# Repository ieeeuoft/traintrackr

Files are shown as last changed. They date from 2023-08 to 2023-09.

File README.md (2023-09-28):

# Traintracker
Traintracker is an interactive way to track regional GO trains on the Lakeshore West and Lakeshore East GO rail corridors. Built using a custom-made PCB that communicates to an API providing real-time train data, this project combines all aspects of electrical engineering, from circuitry to embedded design and programming to software backend systems. 

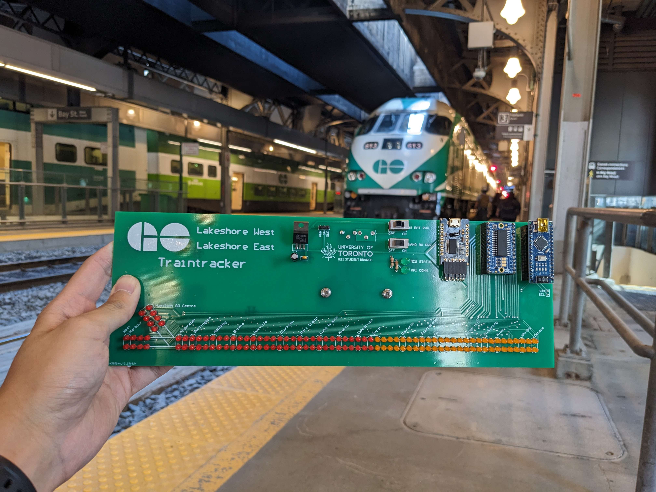
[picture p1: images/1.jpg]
gotrain


##  How It Works
Real-time train locations are displayed on a custom PCB with 130 LEDs representing a rough to-scale map of the two GO train lines. Real-time train location coordinates are pulled from the official GO transit API using a Python script and then sent serially to an Arduino Nano. The Arduino Nano then communicates via I2C an LED driver which powers the LED map. 

The PCB has its own built-in power source - all that is needed for the PCB to start displaying GO trains is a USB connection to a computer running the Python script that calls the GO API. 

The Python script calls the GO API every 10 seconds and maps the location of the trains to specific LEDs on the PCB. A string is then sent serially to the Arduino Nano on the PCB with instructions on which LEDs need to be turned on. The Python script maps the location of trains to LEDs by using the ETA of trains to the next stop and the scheduled amount of time each station-to-station journey takes. 

The Arduino Nano decodes the string sent from the Python script and writes to the LED driver buffer which LEDs need to be powered on. The PCB board updates every 10 seconds, corresponding to the frequency of API calls. 

Watch the board in action here: [Traintracker Demo](https://youtu.be/RSGbkJ9dDE4)

## Background
This project was developed with the support of the University of Toronto IEEE Student Branch over Summer 2023 as a project to demonstrate the technical capabilities of the Tech Team at IEEE. The project was displayed at several club fairs during Frosh Week at the University of Toronto.

The PCB was designed in Altium Designer, and manufactured by JLCPCB. 

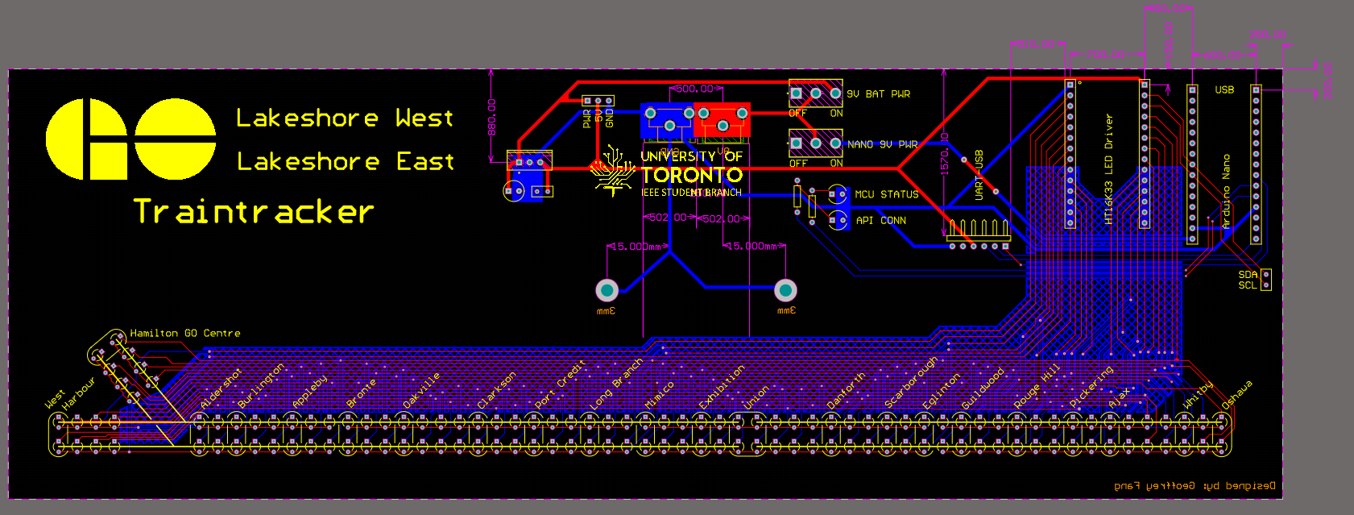
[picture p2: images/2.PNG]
altium

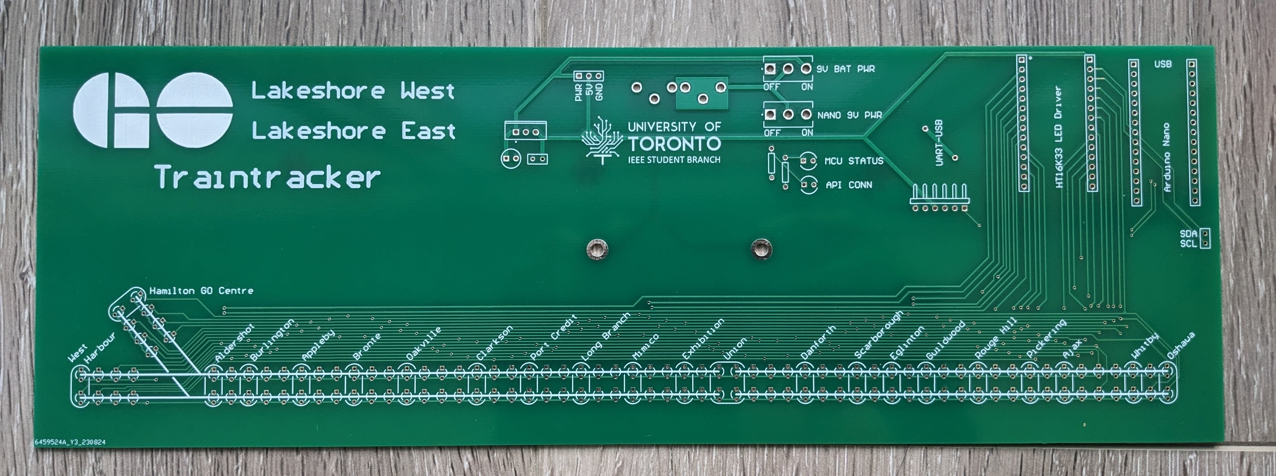
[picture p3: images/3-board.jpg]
manufactured board


The electrical components were sourced from Digikey and Creatron. 
## Acknowledgements
Geoffrey Fang was the project manager and the lead designer of the project from front to back. He focused on the electrical and embedded design of the project. He was also in charge of the logistics of the project, ensuring the funding and components were available when needed during development. 

Scott Hirano focused on the development of the backend Python scripts and provided constant liason with UofT IEEE Student Branch leads. 

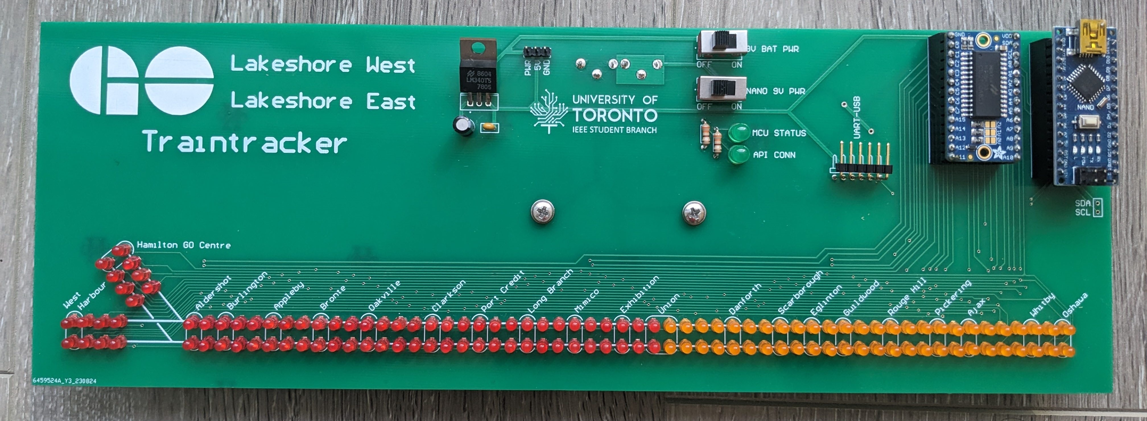
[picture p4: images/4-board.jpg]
completed build


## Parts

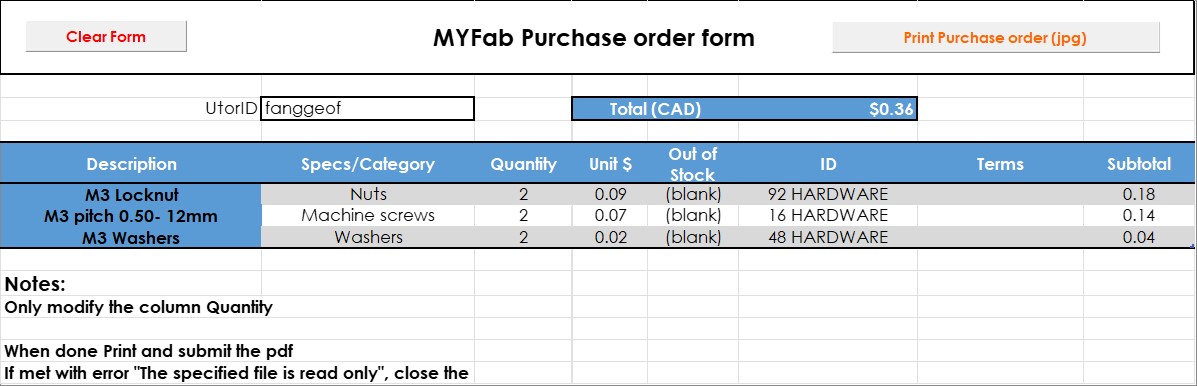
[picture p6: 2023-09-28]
Mechanical/Traintrackr_order.jpg

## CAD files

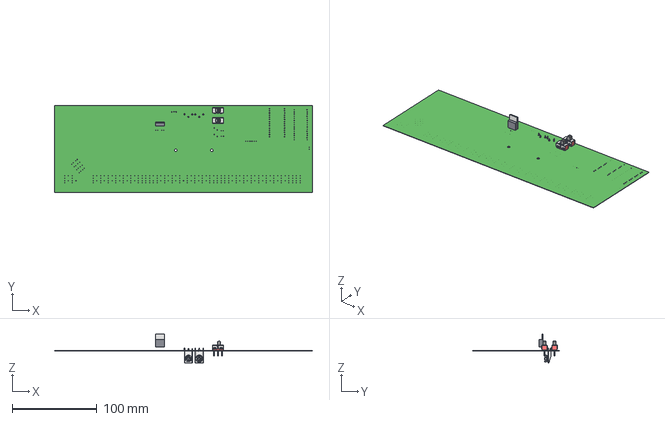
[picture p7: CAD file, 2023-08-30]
Mechanical/traintrackr PCB.step
304.8 x 102.9 x 34.0 mm

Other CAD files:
Mechanical/Beam1.DWG
Mechanical/Beam2.DWG
Mechanical/new_traintrackr_laser.dwg
Mechanical/ArchPair.DWG
Mechanical/traintrackr_laser.dwg

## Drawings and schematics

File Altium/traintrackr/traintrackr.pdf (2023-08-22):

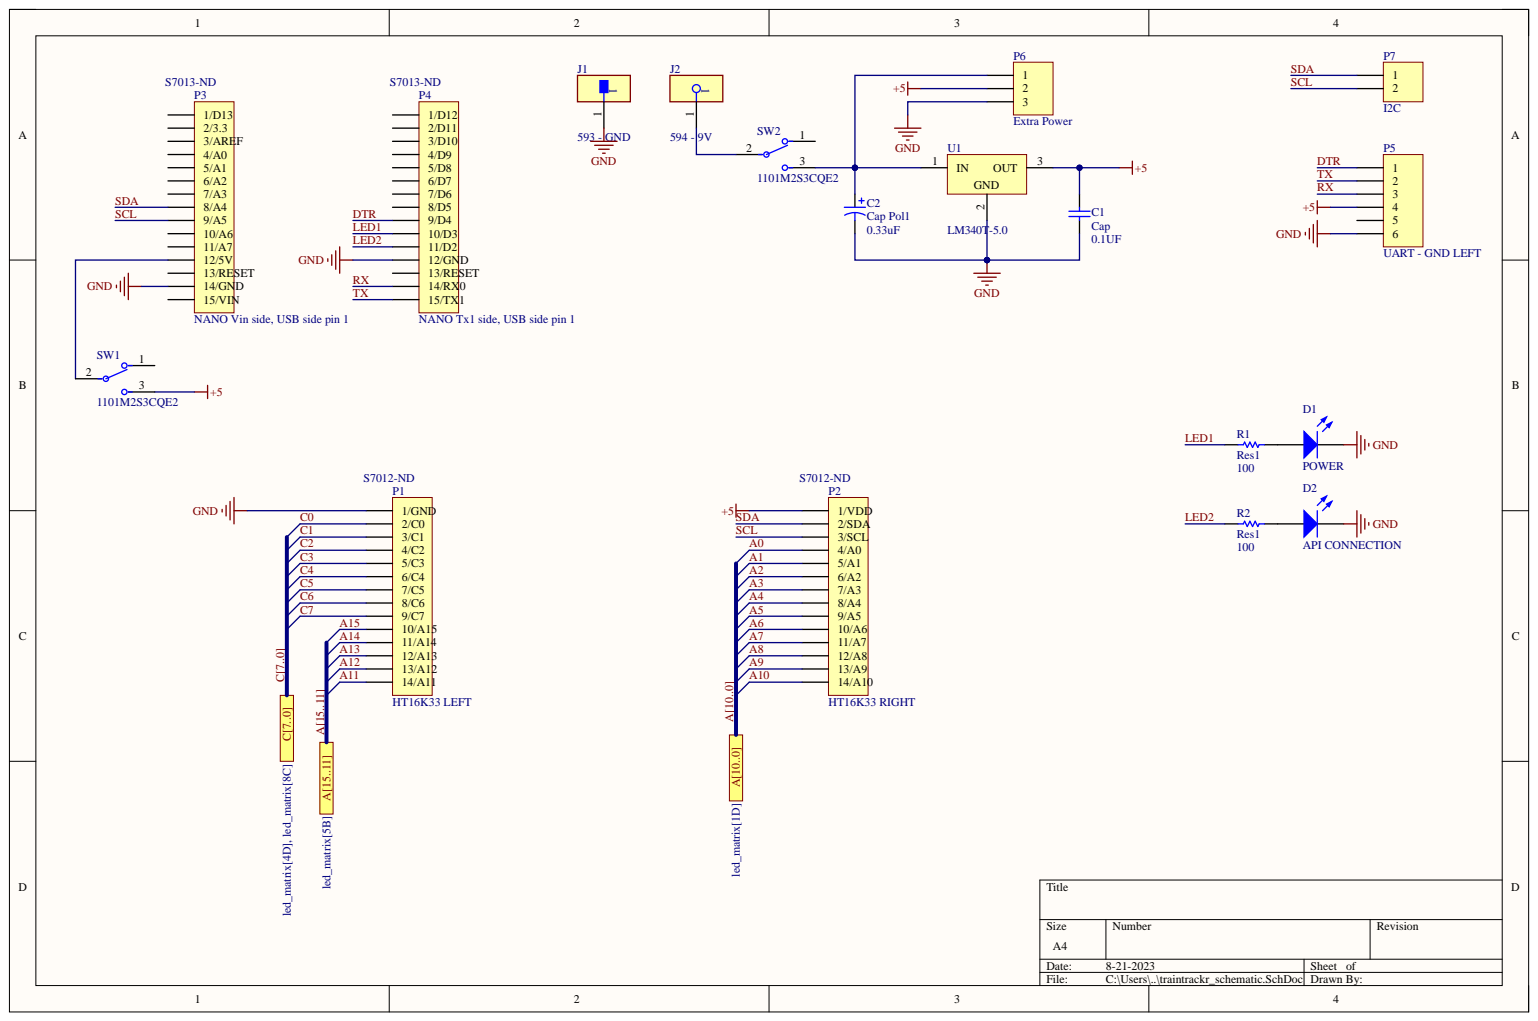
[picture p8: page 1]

API CONNECTION GND GND

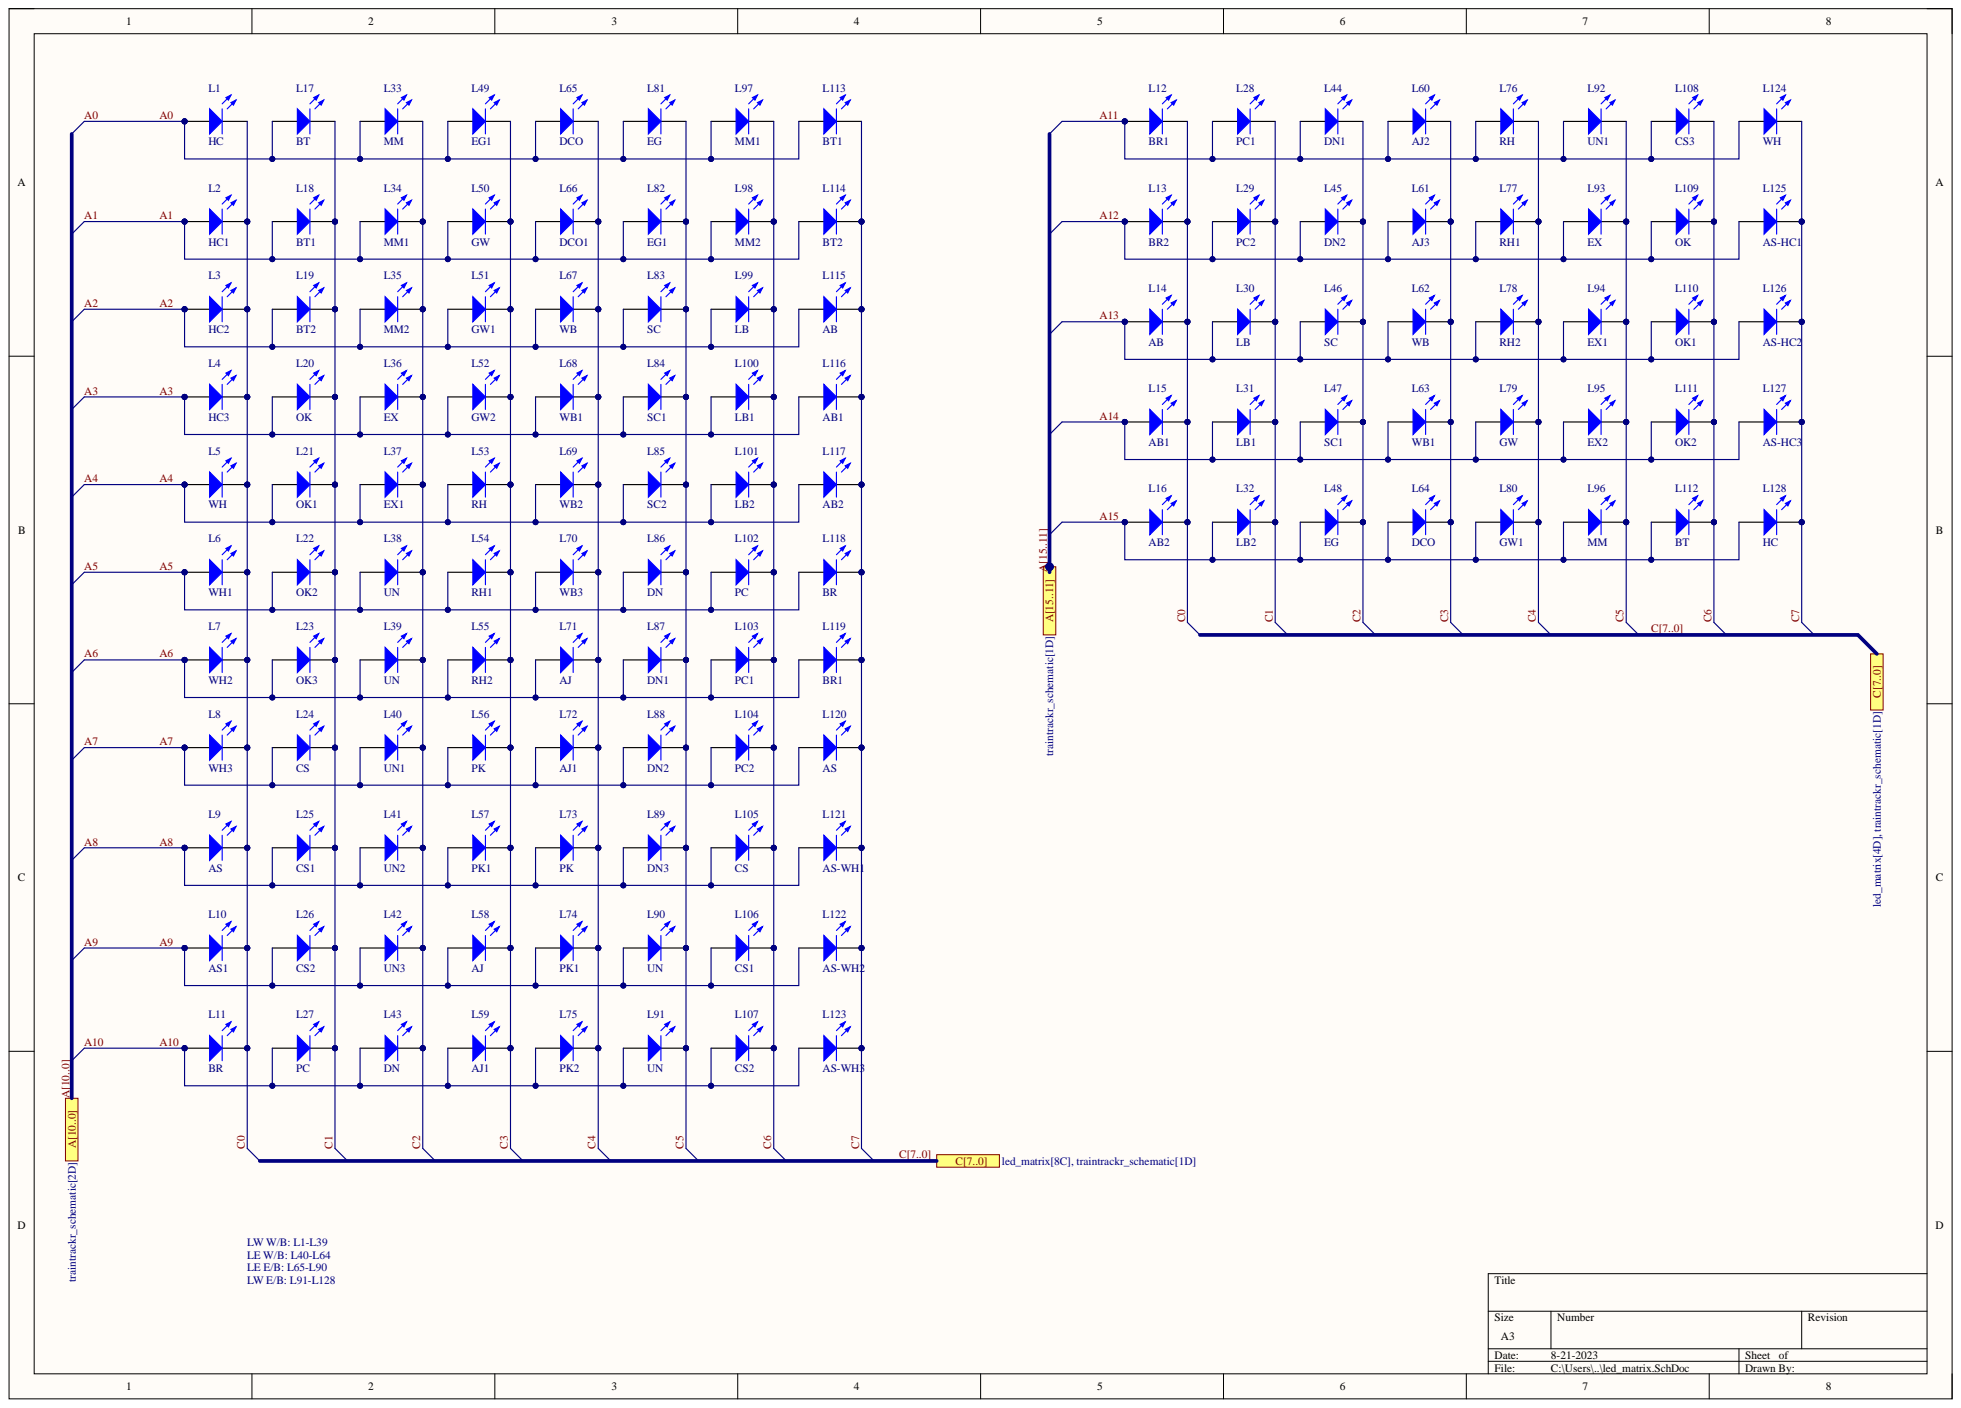
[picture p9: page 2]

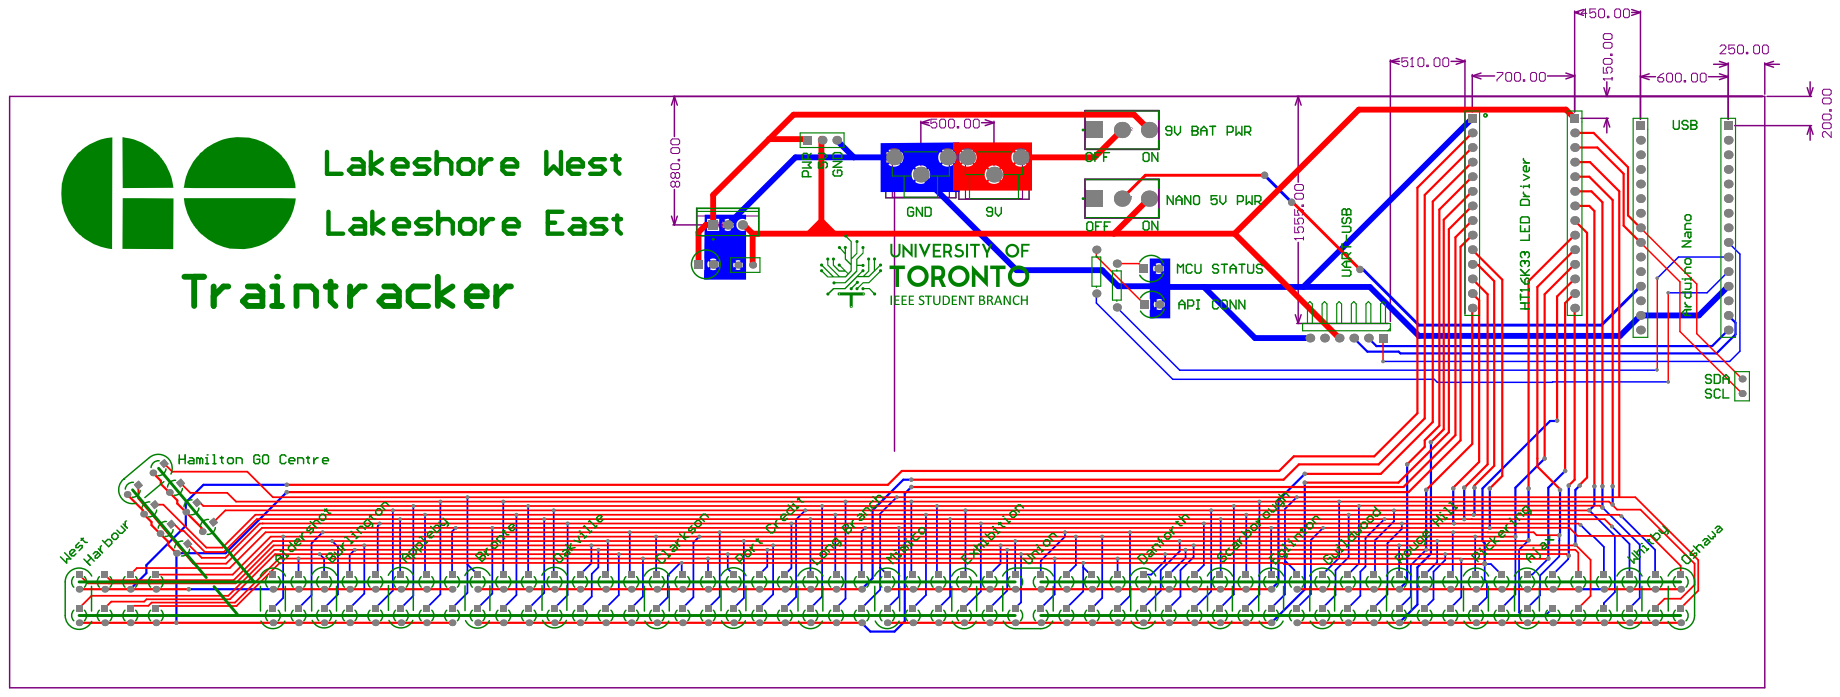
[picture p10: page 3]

Comment | Description | Designator | Footprint | LibRef | Quantity
Cap | Capacitor | C1 | RAD-0.1 | CAP CER 0.1UF 50V X7R RADIAL | 1
Cap Pol1 | Polarized Capacitor (Radial) | C2 | Capacitor 330nF | Cap Pol1 | 1
POWER | Typical RED GaAs LED | D1 | LED_5MM | LED1 | 1
API CONNECTION | Typical RED GaAs LED | D2 | LED_5MM | LED1 | 1
593 - GND | BATTERY CONTACT SNAP 9V PC PIN | J1 | FP-593-MFG | CMP-19636-000031-1 | 1
594 - 9V | BATTERY CONTACT SNAP 9V PC PIN | J2 | FP-594-MFG | CMP-19636-000029-1 | 1
HC | Typical RED GaAs LED | L1, L128 | PCBComponent_1 | LED1 | 2
HC1 | Typical RED GaAs LED | L2 | PCBComponent_1 | LED1 | 1
HC2 | Typical RED GaAs LED | L3 | PCBComponent_1 | LED1 | 1
HC3 | Typical RED GaAs LED | L4 | PCBComponent_1 | LED1 | 1
WH | Typical RED GaAs LED | L5, L124 | PCBComponent_1 | LED1 | 2
WH1 | Typical RED GaAs LED | L6 | PCBComponent_1 | LED1 | 1
WH2 | Typical RED GaAs LED | L7 | PCBComponent_1 | LED1 | 1
WH3 | Typical RED GaAs LED | L8 | PCBComponent_1 | LED1 | 1
AS | Typical RED GaAs LED | L9, L120 | PCBComponent_1 | LED1 | 2
AS1 | Typical RED GaAs LED | L10 | PCBComponent_1 | LED1 | 1
BR | Typical RED GaAs LED | L11, L118 | PCBComponent_1 | LED1 | 2
BR1 | Typical RED GaAs LED | L12, L119 | PCBComponent_1 | LED1 | 2
BR2 | Typical RED GaAs LED | L13 | PCBComponent_1 | LED1 | 1
AB | Typical RED GaAs LED | L14, L115 | PCBComponent_1 | LED1 | 2
AB1 | Typical RED GaAs LED | L15, L116 | PCBComponent_1 | LED1 | 2
AB2 | Typical RED GaAs LED | L16, L117 | PCBComponent_1 | LED1 | 2
BT | Typical RED GaAs LED | L17, L112 | PCBComponent_1 | LED1 | 2
BT1 | Typical RED GaAs LED | L18, L113 | PCBComponent_1 | LED1 | 2
BT2 | Typical RED GaAs LED | L19, L114 | PCBComponent_1 | LED1 | 2
OK | Typical RED GaAs LED | L20, L109 | PCBComponent_1 | LED1 | 2
OK1 | Typical RED GaAs LED | L21, L110 | PCBComponent_1 | LED1 | 2
OK2 | Typical RED GaAs LED | L22, L111 | PCBComponent_1 | LED1 | 2
OK3 | Typical RED GaAs LED | L23 | PCBComponent_1 | LED1 | 1
CS | Typical RED GaAs LED | L24, L105 | PCBComponent_1 | LED1 | 2
CS1 | Typical RED GaAs LED | L25, L106 | PCBComponent_1 | LED1 | 2
CS2 | Typical RED GaAs LED | L26, L107 | PCBComponent_1 | LED1 | 2
PC | Typical RED GaAs LED | L27, L102 | PCBComponent_1 | LED1 | 2
PC1 | Typical RED GaAs LED | L28, L103 | PCBComponent_1 | LED1 | 2
PC2 | Typical RED GaAs LED | L29, L104 | PCBComponent_1 | LED1 | 2
LB | Typical RED GaAs LED | L30, L99 | PCBComponent_1 | LED1 | 2
LB1 | Typical RED GaAs LED | L31, L100 | PCBComponent_1 | LED1 | 2
LB2 | Typical RED GaAs LED | L32, L101 | PCBComponent_1 | LED1 | 2
MM | Typical RED GaAs LED | L33, L96 | PCBComponent_1 | LED1 | 2
MM1 | Typical RED GaAs LED | L34, L97 | PCBComponent_1 | LED1 | 2
MM2 | Typical RED GaAs LED | L35, L98 | PCBComponent_1 | LED1 | 2
EX | Typical RED GaAs LED | L36, L93 | PCBComponent_1 | LED1 | 2
EX1 | Typical RED GaAs LED | L37, L94 | PCBComponent_1 | LED1 | 2
UN | Typical RED GaAs LED | L38, L39, L90, L91 | PCBComponent_1 | LED1 | 4
UN1 | Typical RED GaAs LED | L40, L92 | PCBComponent_1 | LED1 | 2
UN2 | Typical RED GaAs LED | L41 | PCBComponent_1 | LED1 | 1
UN3 | Typical RED GaAs LED | L42 | PCBComponent_1 | LED1 | 1
DN | Typical RED GaAs LED | L43, L86 | PCBComponent_1 | LED1 | 2
DN1 | Typical RED GaAs LED | L44, L87 | PCBComponent_1 | LED1 | 2
DN2 | Typical RED GaAs LED | L45, L88 | PCBComponent_1 | LED1 | 2
SC | Typical RED GaAs LED | L46, L83 | PCBComponent_1 | LED1 | 2
SC1 | Typical RED GaAs LED | L47, L84 | PCBComponent_1 | LED1 | 2
EG | Typical RED GaAs LED | L48, L81 | PCBComponent_1 | LED1 | 2
EG1 | Typical RED GaAs LED | L49, L82 | PCBComponent_1 | LED1 | 2
GW | Typical RED GaAs LED | L50, L79 | PCBComponent_1 | LED1 | 2
GW1 | Typical RED GaAs LED | L51, L80 | PCBComponent_1 | LED1 | 2
GW2 | Typical RED GaAs LED | L52 | PCBComponent_1 | LED1 | 1
RH | Typical RED GaAs LED | L53, L76 | PCBComponent_1 | LED1 | 2
RH1 | Typical RED GaAs LED | L54, L77 | PCBComponent_1 | LED1 | 2
RH2 | Typical RED GaAs LED | L55, L78 | PCBComponent_1 | LED1 | 2
PK | Typical RED GaAs LED | L56, L73 | PCBComponent_1 | LED1 | 2
PK1 | Typical RED GaAs LED | L57, L74 | PCBComponent_1 | LED1 | 2
AJ | Typical RED GaAs LED | L58, L71 | PCBComponent_1 | LED1 | 2
AJ1 | Typical RED GaAs LED | L59, L72 | PCBComponent_1 | LED1 | 2
AJ2 | Typical RED GaAs LED | L60 | PCBComponent_1 | LED1 | 1
AJ3 | Typical RED GaAs LED | L61 | PCBComponent_1 | LED1 | 1
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

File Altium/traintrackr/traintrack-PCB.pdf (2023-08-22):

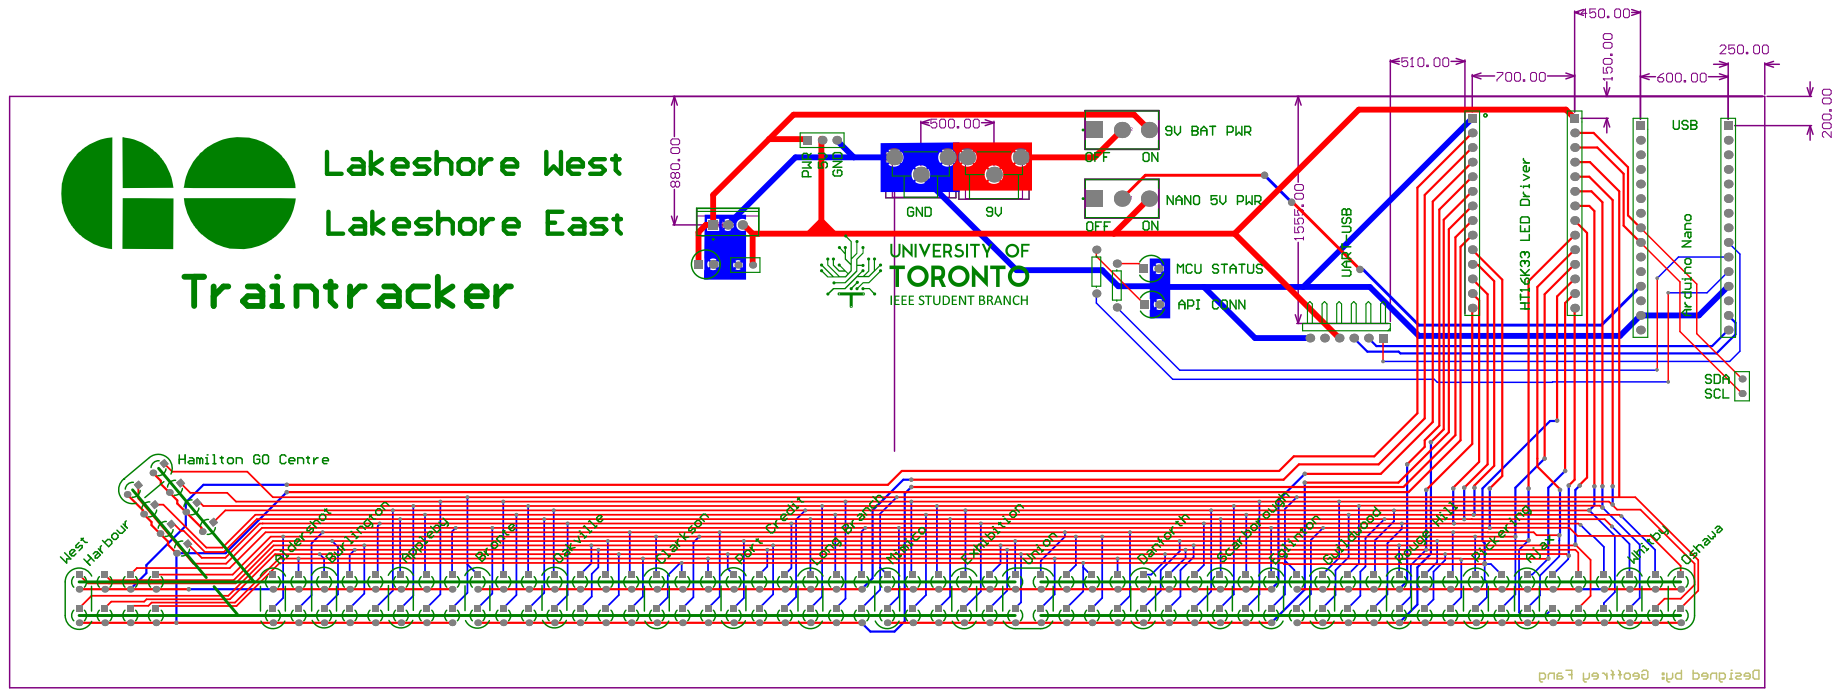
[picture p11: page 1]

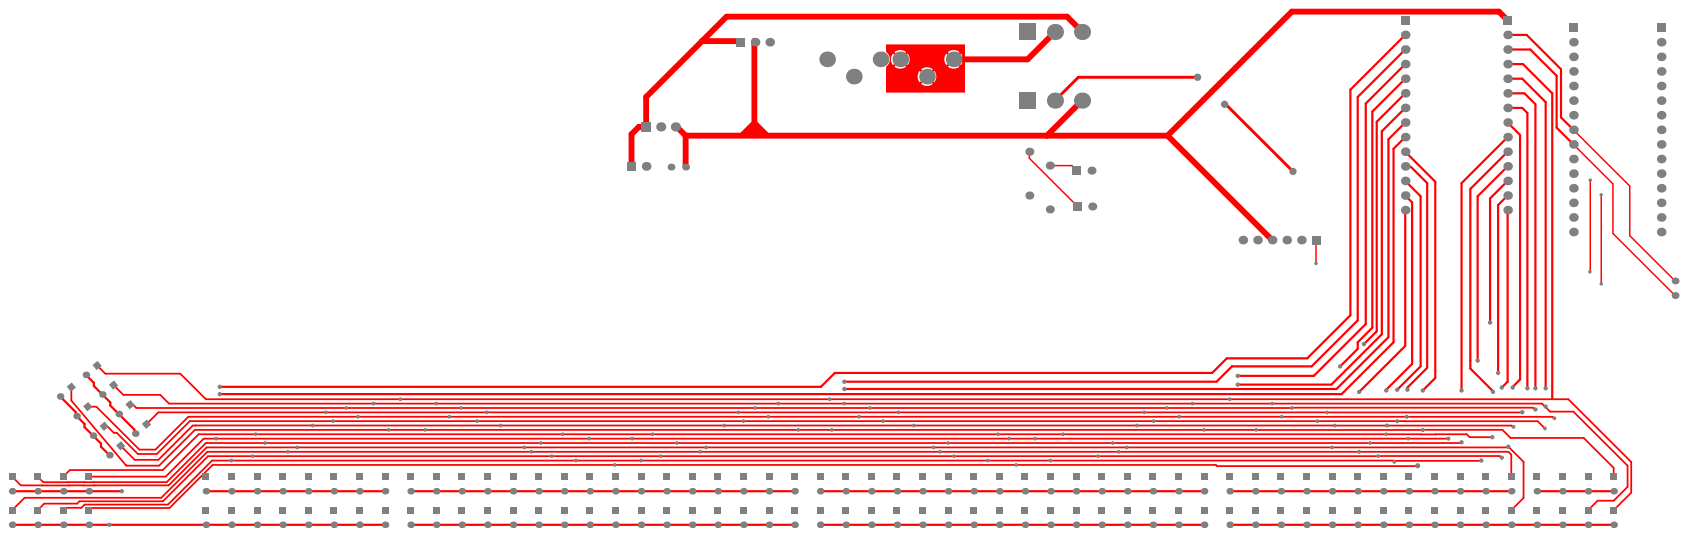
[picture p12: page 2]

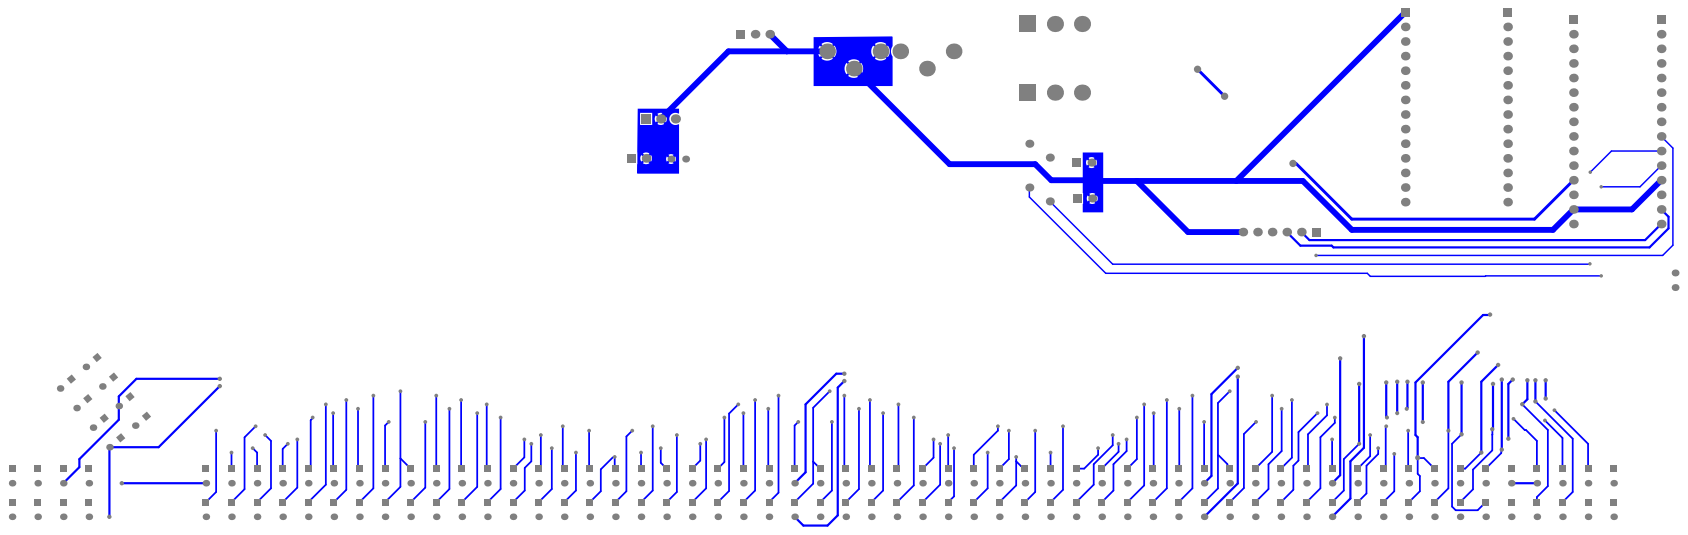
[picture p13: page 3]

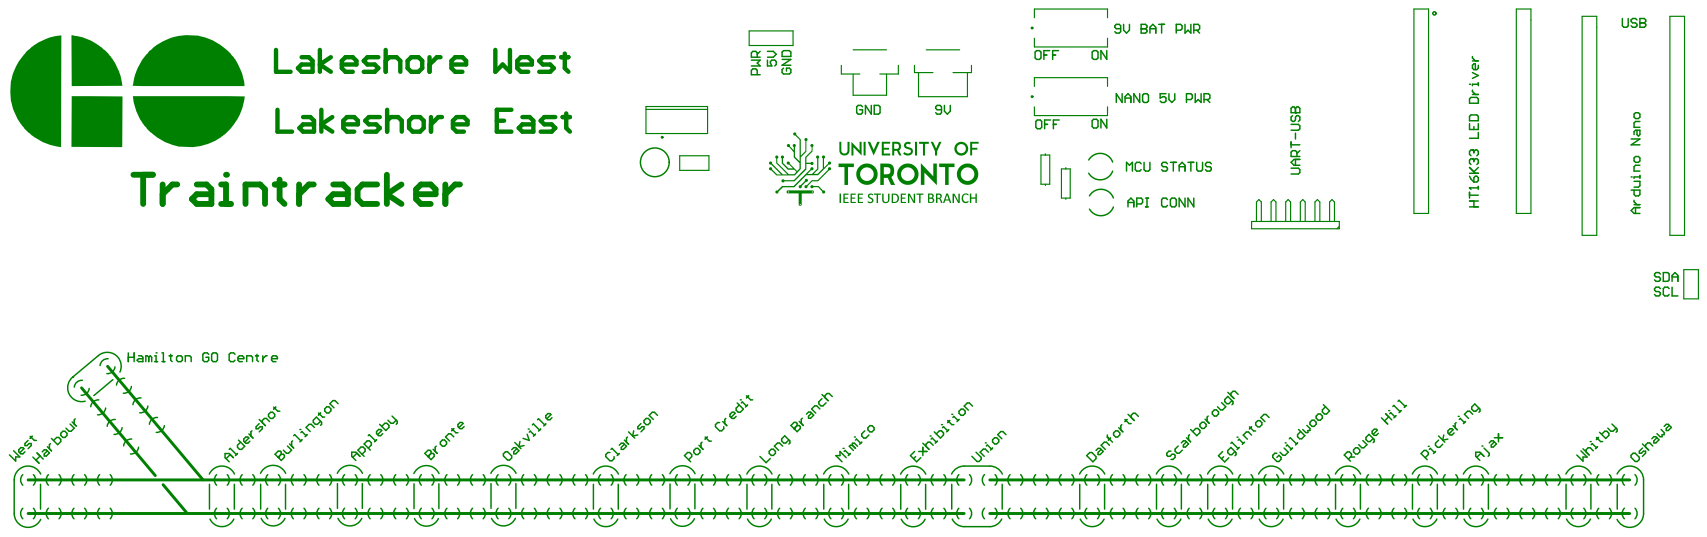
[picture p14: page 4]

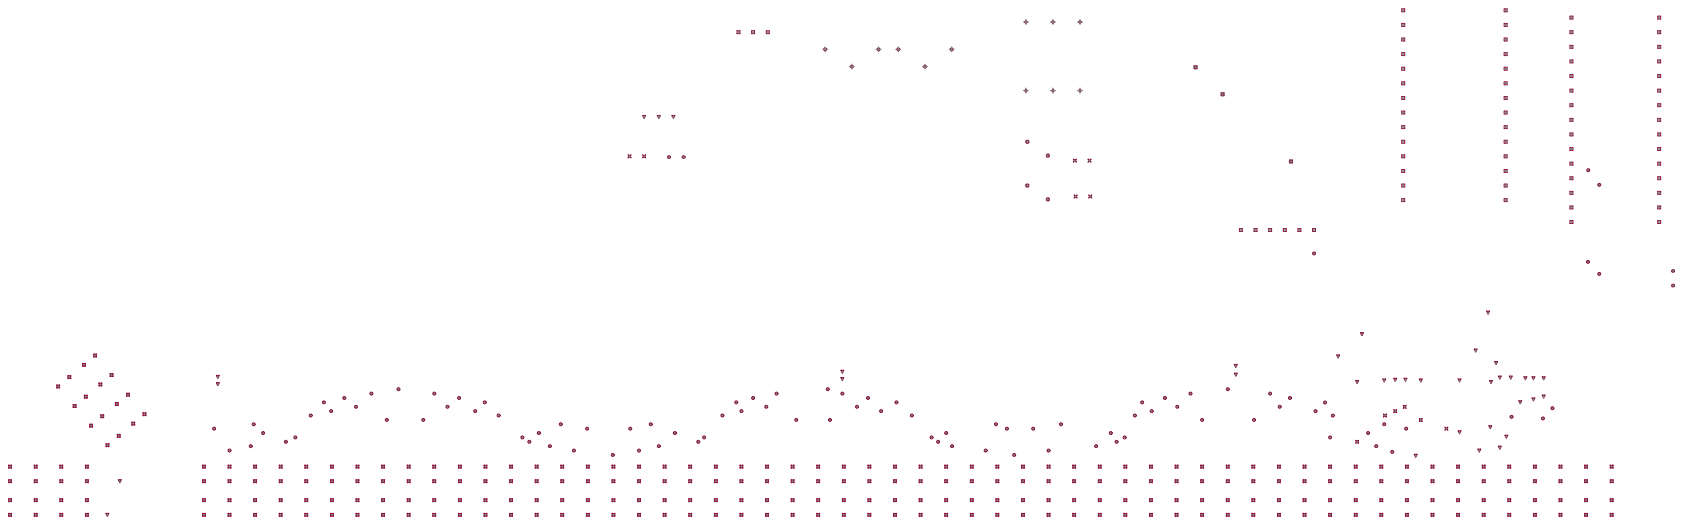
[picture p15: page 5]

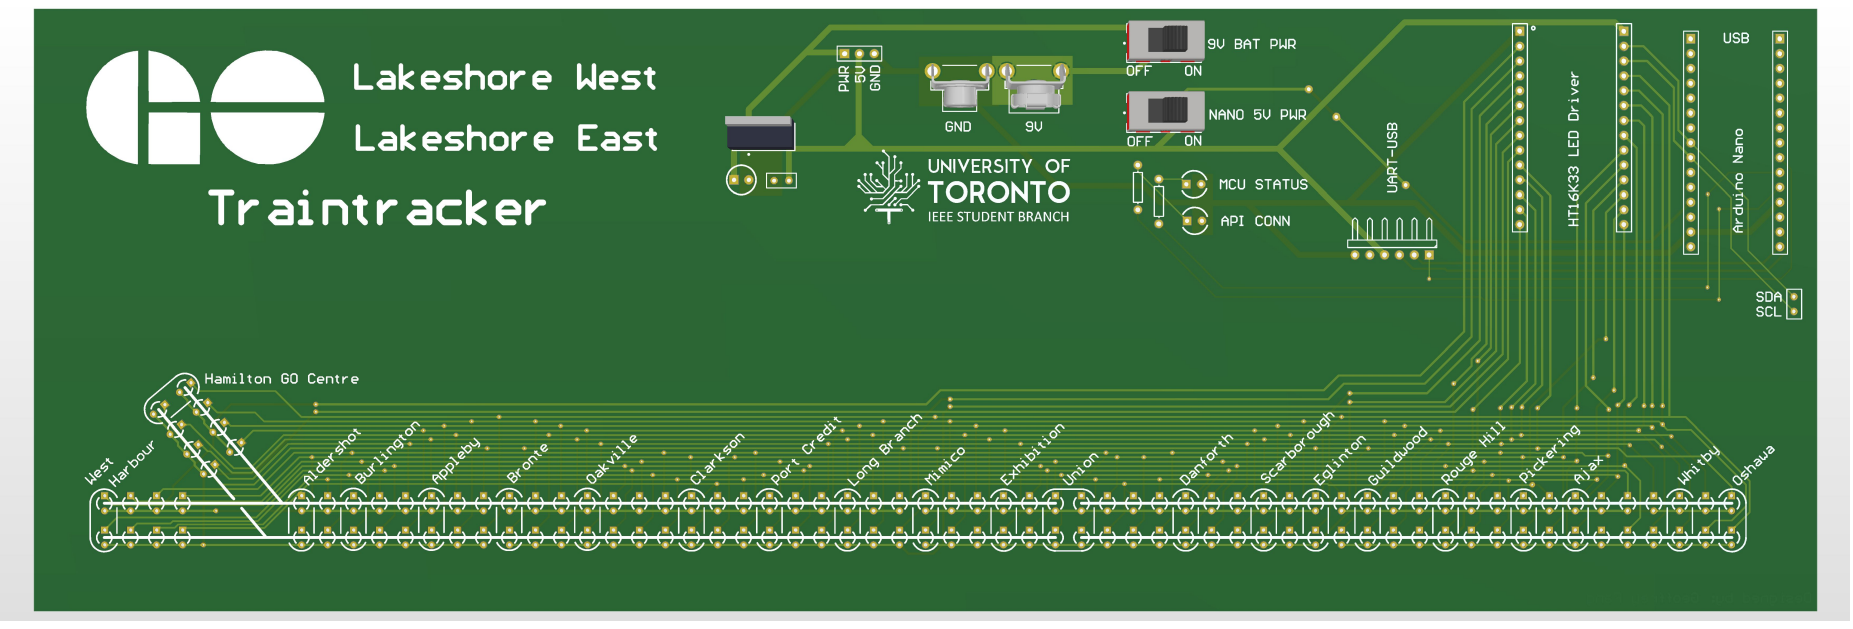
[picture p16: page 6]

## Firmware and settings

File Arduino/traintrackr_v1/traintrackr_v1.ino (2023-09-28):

#include <Wire.h>
#include <Adafruit_GFX.h>
#include "Adafruit_LEDBackpack.h"

#ifndef _BV
  #define _BV(bit) (1<<(bit))
#endif


Adafruit_LEDBackpack matrix = Adafruit_LEDBackpack();

uint8_t counter = 0;
uint16_t delayTime = 200;
int firstTimer = 0;

void setup() {
  Serial.begin(9600);
  matrix.begin(0x70);  // pass in the address
  Serial.println("Arduino on");
  pinMode(2, OUTPUT);   //digital pin 2 = API CONN
  pinMode(3, OUTPUT);   //digital pin 3 = MCU STATUS
  analogWrite(3, 10);   //PWM to reduce brightness
  digitalWrite(2, LOW);
}

void loop() {
  // matrix.displaybuffer[3] = (1<<0);
  // squarebracket = row (C), leftshift = col (A)

  // String received = "A00C1A00C2A00C3A00C0A01C0"; for testing
 
  
  if (Serial.available() > 0) {
    //first clear everything
    for (uint8_t c=0; c<8; c++){
        matrix.displaybuffer[c] = 0;
    }

    String received = Serial.readStringUntil('\n');
    digitalWrite(2, HIGH);
    int a;
    int c;

    int upper_limit = received.length() / 5;
    for (int i = 0; i < upper_limit; i++){
      a = (received[i * 5 + 1] - 48) * 10 + (received[i * 5 + 2] - 48);
      c = received[i * 5 + 4] - 48;
      matrix.displaybuffer[c] |= (1 << a);
    }
    matrix.writeDisplay();
    Serial.println("Received and Board Lit");
    Serial.flush();
    digitalWrite(2, LOW);
  }
}

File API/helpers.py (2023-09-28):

from timings import exportBoardNumberings, exportTrainTimings
import json
import datetime
from all_trips import getAllTrips

def L_to_AC(L):
    if not L:
        return ""
    C = (L - 1) // 16 
    A = (L - 1) % 16
    if A < 10:
        A = "0" + str(A)
    
    return "A" + str(A) + "C" + str(C)
    
def time_to_next_stop(station):
    now = datetime.datetime.timestamp(datetime.datetime.now())
    # The entire object obtained from the first item of "'trip_update' of 'stop_time_update'" 
    # From the trip updates API return

    next_stop = station["departure"]["time"]
    
    diff = (next_stop - now) / 60
    return diff

def value_to_section(value, num_sections):
    adjusted_value = value * num_sections
    for i in range(num_sections):
        if adjusted_value < i:
            return i
    return num_sections

def find_prev_station_boardNum(station, direction):
    # enter station in the form of "HC" or "WR"
    boardNumberings = exportBoardNumberings[direction]
    stationNum = boardNumberings[station]
    for i in range(1,10):
        if stationNum + i in boardNumberings.values():
            return stationNum + i
    return None

def stopped_at_station_to_section(station, direction): 
    station_id = station["stop_id"]
    if station_id == "SCTH":
        return ""
    return exportBoardNumberings[direction][station_id]

def get_all_scheduled_trips_today():
    all_trips = None
    while not all_trips:
        try:
            with open(f"{datetime.date.today().strftime('%Y%m%d')} - Scheduled Trains",'r') as openfile:
                all_trips = json.load(openfile)
                return all_trips
        except:
            getAllTrips()

def scheduled_full_time_between_stations(next_station_id, trip_id, direction):
    all_trips = get_all_scheduled_trips_today()
    all_trips_in_direction = all_trips[direction]
    relevant_trip = None
    for trip in all_trips_in_direction:
        if (trip_id == trip['Number']):
            relevant_trip = trip
            break
    if not relevant_trip:
        print("Unscheduled Trip")
        return None
    for i in range(len(relevant_trip['Stops'])):
        next_stop = relevant_trip['Stops'][i]
        if (next_stop['Code']) == next_station_id:
            previous_stop = relevant_trip['Stops'][i-1]
            break
    next_stop_time = next_stop['Time']
    prev_stop_time = previous_stop['Time']
    next_stop_time = datetime.datetime.strptime(next_stop_time,'%Y-%m-%d %H:%M:%S')
    prev_stop_time = datetime.datetime.strptime(prev_stop_time,'%Y-%m-%d %H:%M:%S')
    minutes_diff = (next_stop_time - prev_stop_time).total_seconds() / 60
    prev_station_id = previous_stop['Code']

    return {
        "prev_station_id": prev_station_id,
        "full_time": minutes_diff
    }
    

def in_transit_station_to_section(station, direction, trip_id):
    # first determine the percentage of the way from the previous station to the next station
    station_id = station["stop_id"]
    est_time_to_station = time_to_next_stop(station)
    # print("est_time_to_station", est_time_to_station)
    real_previous_station = scheduled_full_time_between_stations(station['stop_id'], trip_id, direction)
    
    if real_previous_station:
        full_time_to_station = real_previous_station['full_time']
        previous_station_id = real_previous_station['prev_station_id']
        if previous_station_id == "SCTH":
            return None
        prev_station_boardNum = exportBoardNumberings[direction][previous_station_id]
    else: # edge case: the trip isn't on the schedule
        full_time_to_station = exportTrainTimings[direction][station_id]
        prev_station_boardNum = find_prev_station_boardNum(station_id, direction)
    # print("full_time_to_station", full_time_to_station)
    value = min(max(0 , est_time_to_station/full_time_to_station), 1)

    # now determine the board number
    current_station_boardNum = exportBoardNumberings[direction][station_id]
    # print(current_station_boardNum, prev_station_boardNum)
    
    num_lights = prev_station_boardNum - current_station_boardNum - 1
    # print("num_lights", num_lights)
    
    relative_section = value_to_section(value, num_lights)
    # print("relative_section", relative_section)
    if station_id == "AL" and previous_station_id == "HA": # Edge case: LW train going eastbound to Aldershot
        return 124 + value_to_section(value, 3)
    if station_id == "HA": # Edge case: LW train going westbound to Hamilton Center
        return 1 + value_to_section(value, 3)
    return current_station_boardNum + relative_section

# sample_station = {'stop_id': 'CL', 'arrival': None, 'departure': {'delay': 106, 'time': 1693349686, 'uncertainty': 0}, 'schedule_relationship': 'SCHEDULED'}
# print(in_transit_station_to_section(sample_station, "LWWB"))

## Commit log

2023-08-14 New practice files for LED driver
2023-08-22 New altium files, arduino testing code
    [LED_3MM.PcbLib, Miscellaneous Devices.PcbLib, Miscellaneous Devices.SchLib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]
2023-08-22 Update to Altium files
    [traintrackr.PcbDoc]
2023-08-23 Final version of PCB design
    [traintrackr.GBL, traintrackr.GBO, traintrackr.GBS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]
2023-08-30 Added mechanical files
    [ArchPair.DWG, Beam1.DWG, Beam2.DWG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]
2023-09-01 backend logic working, need to test with arduino
2023-09-02 connection to arduino tested and working
2023-09-04 port doesn't close until program ends
    [script.py]
2023-09-04 Added new arduino LED code for status lights
2023-09-05 fixed deadheading trains issue
    [script.py]
2023-09-05 Fixed python bug and updated bug report
    [helpers.py]
2023-09-15 Clean up
    [traintrackr - Copy10.PcbDoc]
